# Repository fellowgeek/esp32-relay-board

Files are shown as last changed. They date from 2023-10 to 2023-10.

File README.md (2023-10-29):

# ESP32 Relay Board
This [WeMos D1 Mini ESP32](https://www.amazon.com/DORHEA-Bluetooth-Internet-Development-Functional/dp/B08ND91YB8/) Relay Board features 6 channels and is compatible with both 24V AC and 5V DC power sources. Specifically designed as a seamless replacement for sprinkler controller systems, this board offers straightforward configurability using jumpers. These jumpers provide the flexibility to set it up as either standalone relays or common input relays, making it an adaptable solution for various applications.

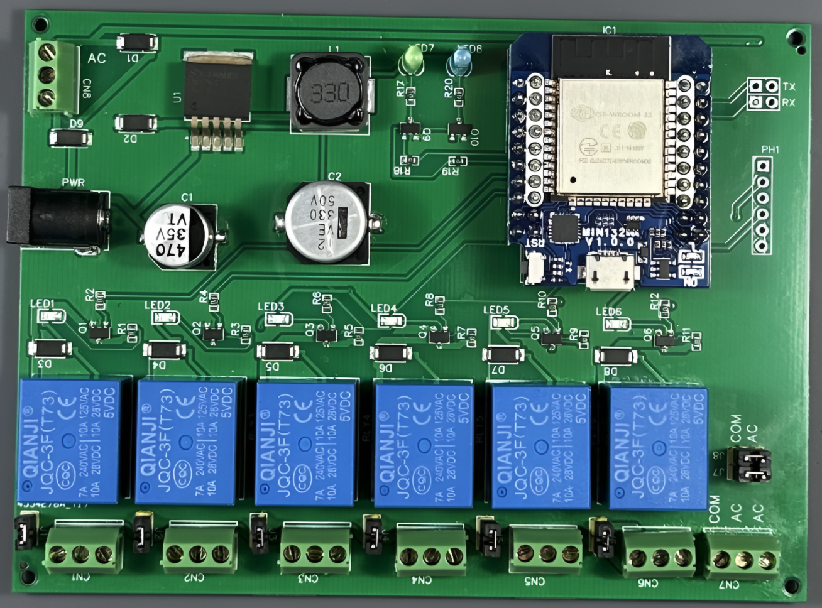
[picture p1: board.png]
Board

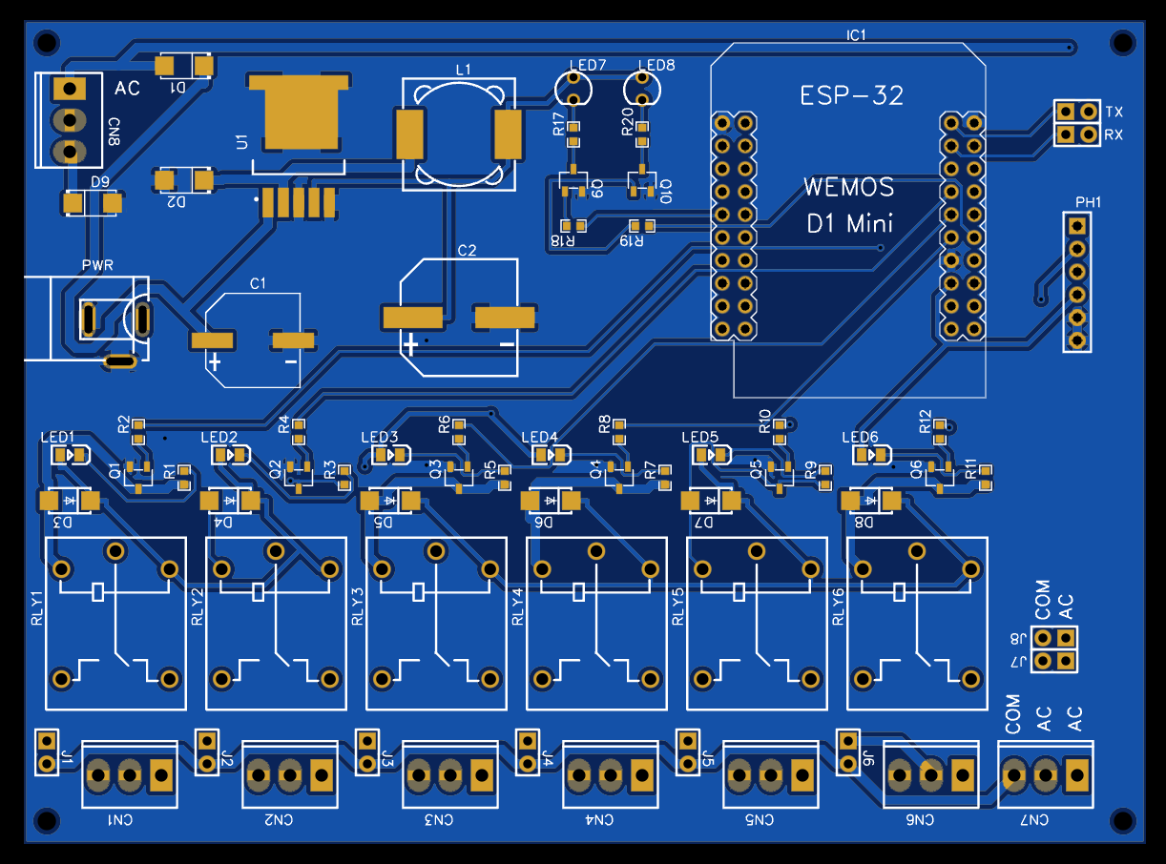
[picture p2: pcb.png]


# BOM

|Line|Name |Designator |Footprint |Quantity|
|----|---|---|---|---|
|1 |470uF |C1 |CAP-SMD_BD10.0-L10.3-W10.3-LS11.3-FD|1 |
|2 |330uF |C2 |CAP-SMD_BD12.5-L13.0-W13.0-LS13.7-FD|1 |
|3 |1X3 |CN1,CN2,CN3,CN4,CN5,CN6,CN7,CN8|TERMINAL-BLOCK 3.5X3 |8 |
|4 |SS24 |D1,D2,D9 |SMA_L4.3-W2.6-LS5.2-RD |3 |
|5 |DIODE |D3,D4,D5,D6,D7,D8 |DO-214AC_L4.3-W2.7-LS5.3-RD |6 |
|6 |[WEMOS-D1-MINI-ESP32](https://www.amazon.com/DORHEA-Bluetooth-Internet-Development-Functional/dp/B08ND91YB8/)|IC1 |WEMOS-D1-MINI-ESP32 |1 |
|7 |Jumper |J1,J2,J3,J4,J5,J6,J7,J8,RX,TX  |HDR-TH_2P-P2.54-V-M-1 |10 |
|8 |33uH |L1 |IND-SMD_L12.3-W12.3 |1 |
|9 |17-21SUYC/TR8 |LED1,LED2,LED3,LED4,LED5,LED6  |LED0805-R-RD |6 |
|10  |LED-TH |LED7,LED8 |LED-TH_BD3.0_RED |2 |
|11  |Header 6x1 |PH1 |PINHEADER_06X1 |1 |
|12  |POWER-JACK |PWR |DC-IN-TH_POWER-JACK |1 |
|13  |AO3400A |Q1,Q2,Q3,Q4,Q5,Q6,Q9,Q10 |SOT-23-3_L2.9-W1.6-P1.90-LS2.8-BR |8 |
|14  |470Ω |R1 |R0603 |1 |
|15  |470Ω |R2,R4,R6,R8,R10,R12,R18,R19 |R0603 |8 |
|16  |470Ω |R3,R5,R7,R9,R11,R17,R20 |R0603 |7 |
|17  |5V RELAY |RLY1,RLY2,RLY3,RLY4,RLY5,RLY6  |RELAY-TH_RELAY-SPST |6 |
|18  |LM2596SX-5.0/NOPB  |U1 |TO-263-5_L10.2-W8.9-P1.70-TL |1 |

# Schematics
Schematic

# Links:

Open Source Hardware Lab project: https://oshwlab.com/fellowgeek/esp-relay-board

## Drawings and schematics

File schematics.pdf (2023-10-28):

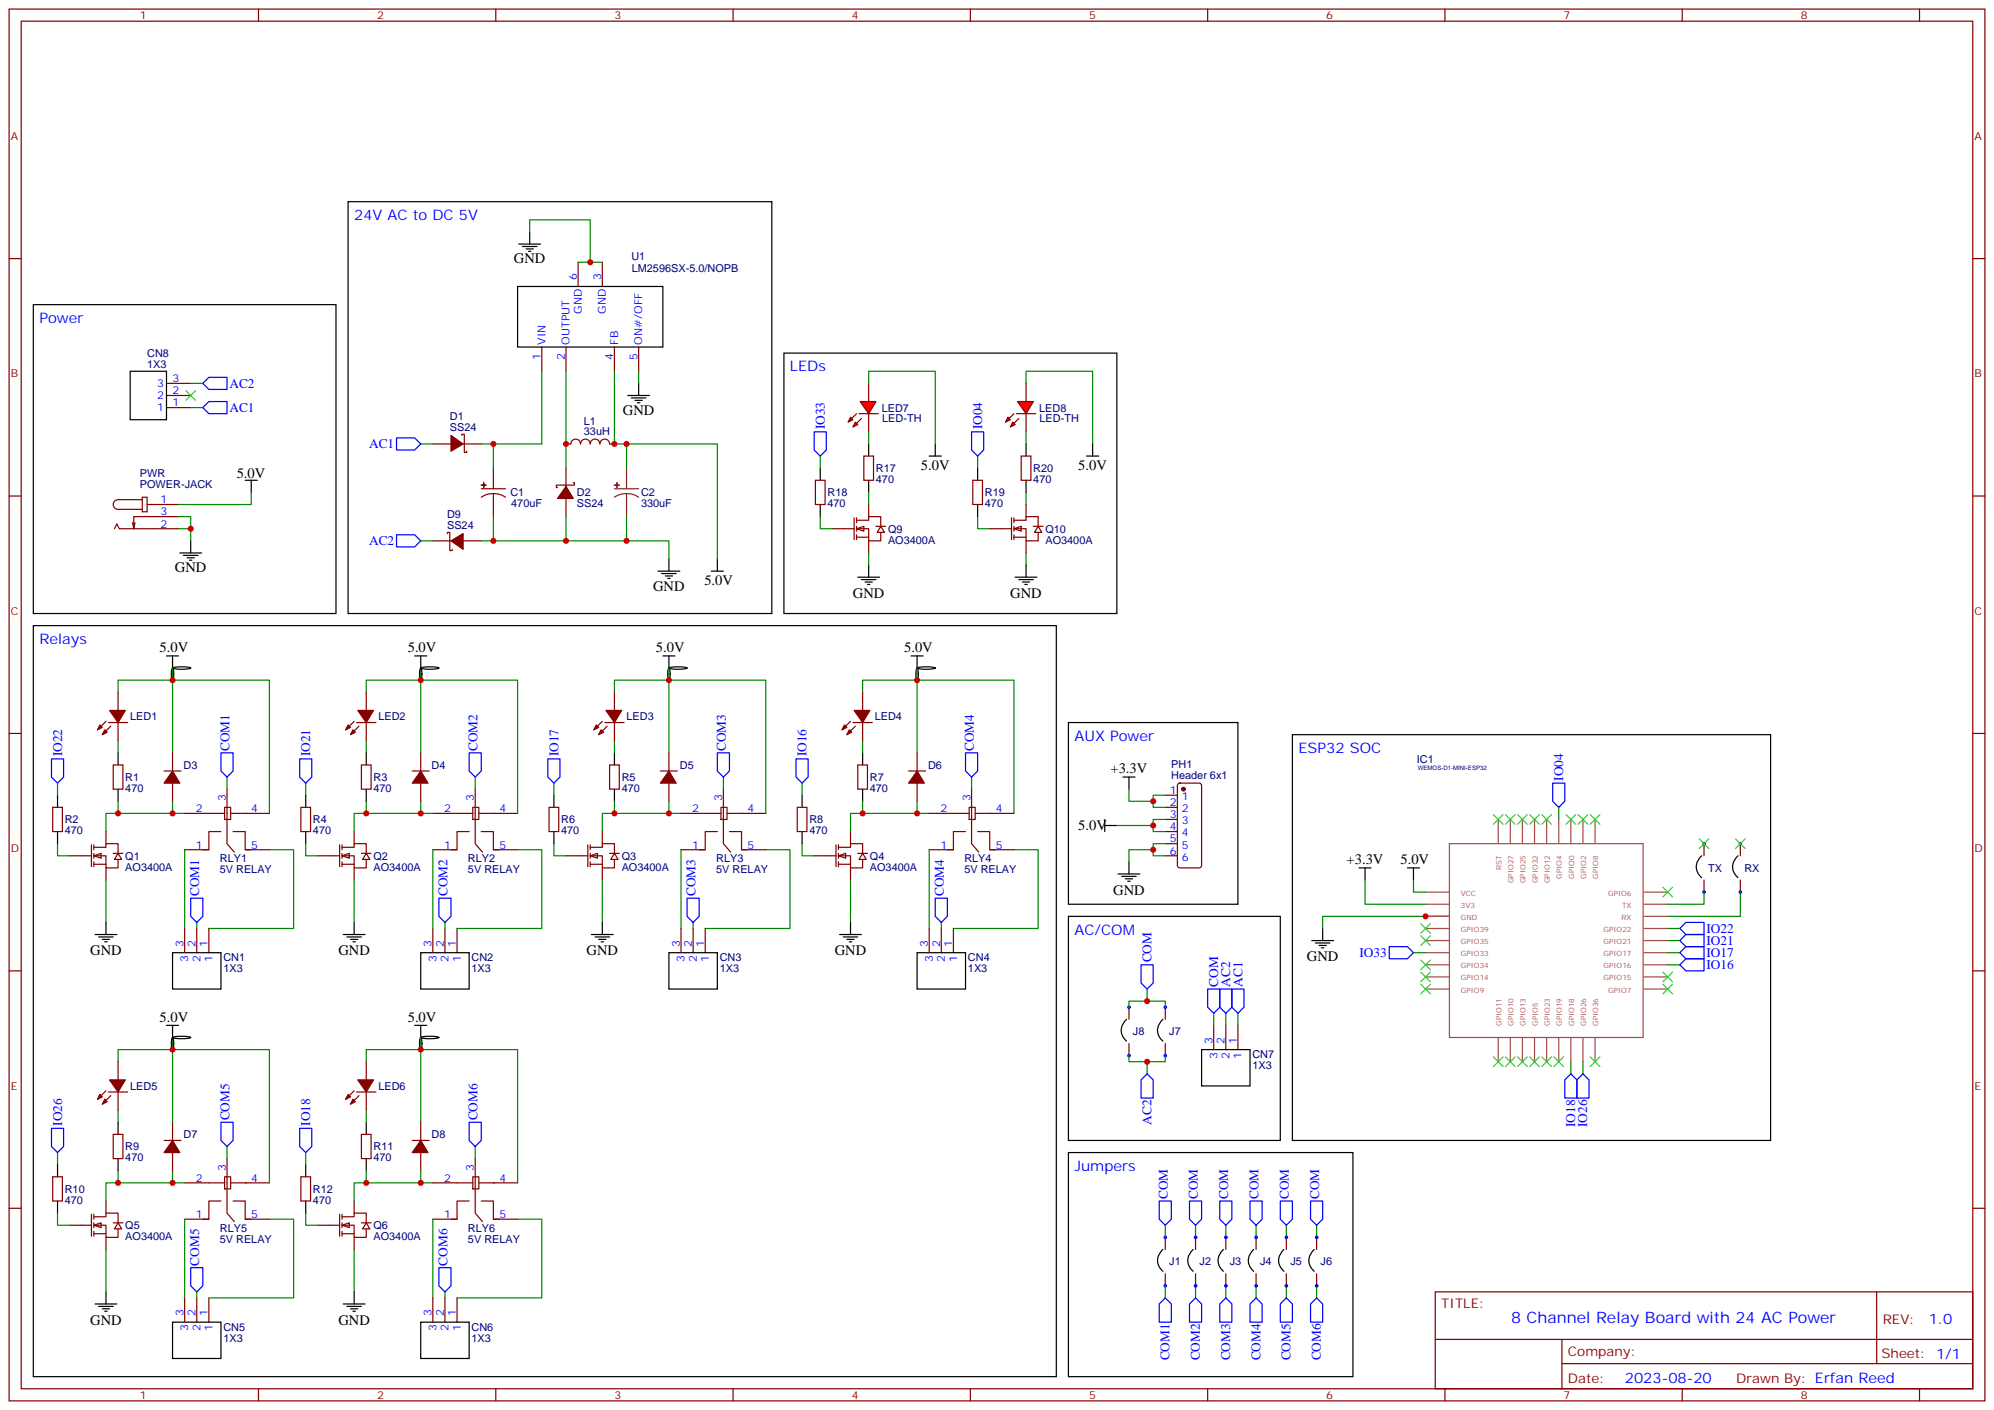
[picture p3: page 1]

Drawn By: Erfan Reed

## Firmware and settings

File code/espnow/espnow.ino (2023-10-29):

/*

To test configure another ESP8266 or 32 and send an ESPNOW message to the boradcast address ff:ff:ff:ff:ff:ff
make sure the message is formatted like this:

ESPNOW message format: >{MAC},{COMMAND}<

example (assuming your device's MAC address is aa:bb:cc:11:22:33):
uint8_t broadcastAddress[] = {0xff, 0xff, 0xff, 0xff, 0xff, 0xff};

// send the sommand to activate relay 1
String message = ">aa:bb:cc:11:22:33,RLC1,1<";
message.toCharArray(payload, message.length() + 1);
esp_now_send(broadcastAddress, (uint8_t *) &payload, sizeof(payload));

// send the sommand to perform a board test
String message = ">aa:bb:cc:11:22:33,TEST<";
message.toCharArray(payload, message.length() + 1);
esp_now_send(broadcastAddress, (uint8_t *) &payload, sizeof(payload));

*/

#include <WiFi.h>
#include <esp_now.h>

// Debug flag
bool debug = false;
// Store the device's MAC address 
String MAC;
// Store the last received command
String lastCommand = "";
// Buffer to hold payload data
char payload[64];
// Timing variables for sending periodic ping messages
unsigned long lastTimePing = 0;
unsigned long timerPing = 55000;
// Broadcast MAC address
uint8_t broadcastAddress[] = {0xff, 0xff, 0xff, 0xff, 0xff, 0xff};
// Information about the ESP-NOW peer
esp_now_peer_info_t peerInfo;

// Define GPIO pins for relays and LEDs
const int RLY1 = 22;
const int RLY2 = 21;
const int RLY3 = 17;
const int RLY4 = 16;
const int RLY5 = 26;
const int RLY6 = 18;
const int LED1 = 33;
const int LED2 = 4;

// Function to reset the state of relays and LEDs
void resetBoard() {
    // Reset all relays and LEDs
    if(debug == true) { 
        Serial.println("setting everything: LOW"); 
    }
    digitalWrite(RLY1, LOW);
    digitalWrite(RLY2, LOW);
    digitalWrite(RLY3, LOW);
    digitalWrite(RLY4, LOW);
    digitalWrite(RLY5, LOW);
    digitalWrite(RLY6, LOW);
    digitalWrite(LED1, LOW);
    digitalWrite(LED2, LOW);
}

// Function to test the board by toggling relays and LEDs
void testBoard() {
    // Reset the board
    resetBoard();
    delay(2500);

    // Test each relay by setting it to HIGH
    if(debug == true) { Serial.println("setting Relay 1: HIGH"); }
    digitalWrite(RLY1, HIGH);
    delay(1000);

    if(debug == true) { Serial.println("setting Relay 2: HIGH"); }
    digitalWrite(RLY2, HIGH);
    delay(1000);

    if(debug == true) { Serial.println("setting Relay 3: HIGH"); }
    digitalWrite(RLY3, HIGH);
    delay(1000);

    if(debug == true) { Serial.println("setting Relay 4: HIGH"); }
    digitalWrite(RLY4, HIGH);
    delay(1000);

    if(debug == true) { Serial.println("setting Relay 5: HIGH"); }
    digitalWrite(RLY5, HIGH);
    delay(1000);

    if(debug == true) { Serial.println("setting Relay 6: HIGH"); }
    digitalWrite(RLY6, HIGH);
    delay(1000);

    // Test each LED by setting it to HIGH
    if(debug == true) { Serial.println("setting LED 1: HIGH"); }
    digitalWrite(LED1, HIGH);
    delay(1000);

    if(debug == true) { Serial.println("setting LED 2: HIGH"); }
    digitalWrite(LED2, HIGH);
    delay(1000);

    // Reset the board again
    delay(2500);
    resetBoard();

    // Reboot the ESP
    ESP.restart();
}

// Function to update the state of a relay
void updateRelay(int relay, int state) {
    int relays[] = {RLY1, RLY2, RLY3, RLY4, RLY5, RLY6};
    for (int x = 0; x < 6; x++) {
        if (relays[x] == relay) {
            digitalWrite(relay, state);
        }
    }
}

// Callback function for handling received data
void OnDataRecv(const uint8_t *mac, const uint8_t *incomingData, int data_len) {
    // Copy the incoming data to the payload buffer
    memcpy(&payload, incomingData, sizeof(payload));
    // Convert the sender's MAC address to a string
    char macStr[18];
    snprintf(macStr, sizeof(macStr), "%02x:%02x:%02x:%02x:%02x:%02x", mac[0], mac[1], mac[2], mac[3], mac[4], mac[5]);

    // Find the delimiter in the payload
    int delimiter;
    String payloadString = payload;
    delimiter = payloadString.indexOf(",");

    if (delimiter != -1) {
        // Extract the target MAC address and command from the payload
        String targetMAC = payloadString.substring(0, delimiter);
        String command = payloadString.substring(delimiter + 1, payloadString.length());

        // Check if the command is intended for this device
        if (targetMAC != MAC) {
            return;
        }

        // Check if this is a duplicate command 
        if (command == lastCommand) {
            if (debug == true) {
                Serial.println("duplicate command ignored: " + command);
            }
            return;
        } else {
            lastCommand = command;
        }

        if (debug == true) {
            Serial.println("processing command: " + command);
        }

        // Blink the LED on command received
        digitalWrite(LED1, HIGH);
        delay(100);
        digitalWrite(LED1, LOW);

        // Handle reboot command
        if (command == "REBOOT") {
            ESP.restart();
        }

        // Handle relay control commands
        if (command == "RLY1,1") { updateRelay(RLY1, HIGH); }
        if (command == "RLY1,0") { updateRelay(RLY1, LOW); }
        if (command == "RLY2,1") { updateRelay(RLY2, HIGH); }
        if (command == "RLY2,0") { updateRelay(RLY2, LOW); }
        if (command == "RLY3,1") { updateRelay(RLY3, HIGH); }
        if (command == "RLY3,0") { updateRelay(RLY3, LOW); }
        if (command == "RLY4,1") { updateRelay(RLY4, HIGH); }
        if (command == "RLY4,0") { updateRelay(RLY4, LOW); }
        if (command == "RLY5,1") { updateRelay(RLY5, HIGH); }
        if (command == "RLY5,0") { updateRelay(RLY5, LOW); }
        if (command == "RLY6,1") { updateRelay(RLY6, HIGH); }
        if (command == "RLY6,0") { updateRelay(RLY6, LOW); }

        // Handle a forced ping
        if (command == "PING") {
            String message = "RLC1,PING";
            message.toCharArray(payload, message.length() + 1);
            esp_now_send(broadcastAddress, (uint8_t *) &payload, sizeof(payload));
        }

        // Handle test command
        if (command == "TEST") {
            testBoard();
        }
    }
}

// Callback function for handling sent data
void OnDataSent(const uint8_t *mac_addr, esp_now_send_status_t status) {
    if(debug == true) {
        Serial.println("ESPNOW message sent.");
    }

    // Blink the LED on message sent
    digitalWrite(LED2, HIGH);
    delay(100);
    digitalWrite(LED2, LOW);
}

// System setup
void setup() {
    // Begin serial IO
    Serial.begin(115200);
    delay(random(1000, 5000));

    // Setup GPIO pins and set their initial states
    pinMode(RLY1, OUTPUT);
    pinMode(RLY2, OUTPUT);
    pinMode(RLY3, OUTPUT);
    pinMode(RLY4, OUTPUT);
    pinMode(RLY5, OUTPUT);
    pinMode(RLY6, OUTPUT);
    pinMode(LED1, OUTPUT);
    pinMode(LED2, OUTPUT);
    digitalWrite(RLY1, LOW);
    digitalWrite(RLY2, LOW);
    digitalWrite(RLY3, LOW);
    digitalWrite(RLY4, LOW);
    digitalWrite(RLY5, LOW);
    digitalWrite(RLY6, LOW);
    digitalWrite(LED1, LOW);
    digitalWrite(LED2, LOW);

    // Configure the device as a Wi-Fi station
    WiFi.mode(WIFI_STA);
    WiFi.disconnect();

    // Disable sleep mode
    WiFi.setSleep(false);

    // Get the device's MAC address
    MAC = WiFi.macAddress();
    MAC.toLowerCase();
    Serial.println("MAC: " + MAC);

    // Initialize ESP-NOW
    if (esp_now_init() != 0) {
      Serial.println("error initializing ESP-NOW");
      delay(1000);
      ESP.restart();
    }

    // Register callback functions for received and sent data
    esp_now_register_recv_cb(OnDataRecv);
    esp_now_register_send_cb(OnDataSent);

    // Register an ESP-NOW peer
    memcpy(peerInfo.peer_addr, broadcastAddress, 6);
    peerInfo.channel = 0;
    peerInfo.encrypt = false;
    if (esp_now_add_peer(&peerInfo) != ESP_OK){
      Serial.println("failed to add peer.");
      delay(1000);
      ESP.restart();
    }
}

// Main loop
void loop() {
    // Periodically send ping messages
    if ((millis() - lastTimePing) > timerPing) {
        String message = "PING,RLC1";
        message.toCharArray(payload, message.length() + 1);
        esp_now_send(broadcastAddress, (uint8_t *) &payload, sizeof(payload));
        lastTimePing = millis();
    }
}
